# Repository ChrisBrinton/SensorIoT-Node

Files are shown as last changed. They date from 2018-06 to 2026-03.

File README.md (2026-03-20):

# SensorIoT-Node (Deprecated)

> **This repository has been consolidated into [SensorIoT-GW](https://github.com/ChrisBrinton/SensorIoT-GW).**
>
> All sensor node firmware and PCB designs now live under `firmware/node/` and `PCBs/node/` in the consolidated repo.
> This repository is kept for historical reference only.

## Original Description
# SensorIoT-Node
The sensor nodes for the SensorIoT environment

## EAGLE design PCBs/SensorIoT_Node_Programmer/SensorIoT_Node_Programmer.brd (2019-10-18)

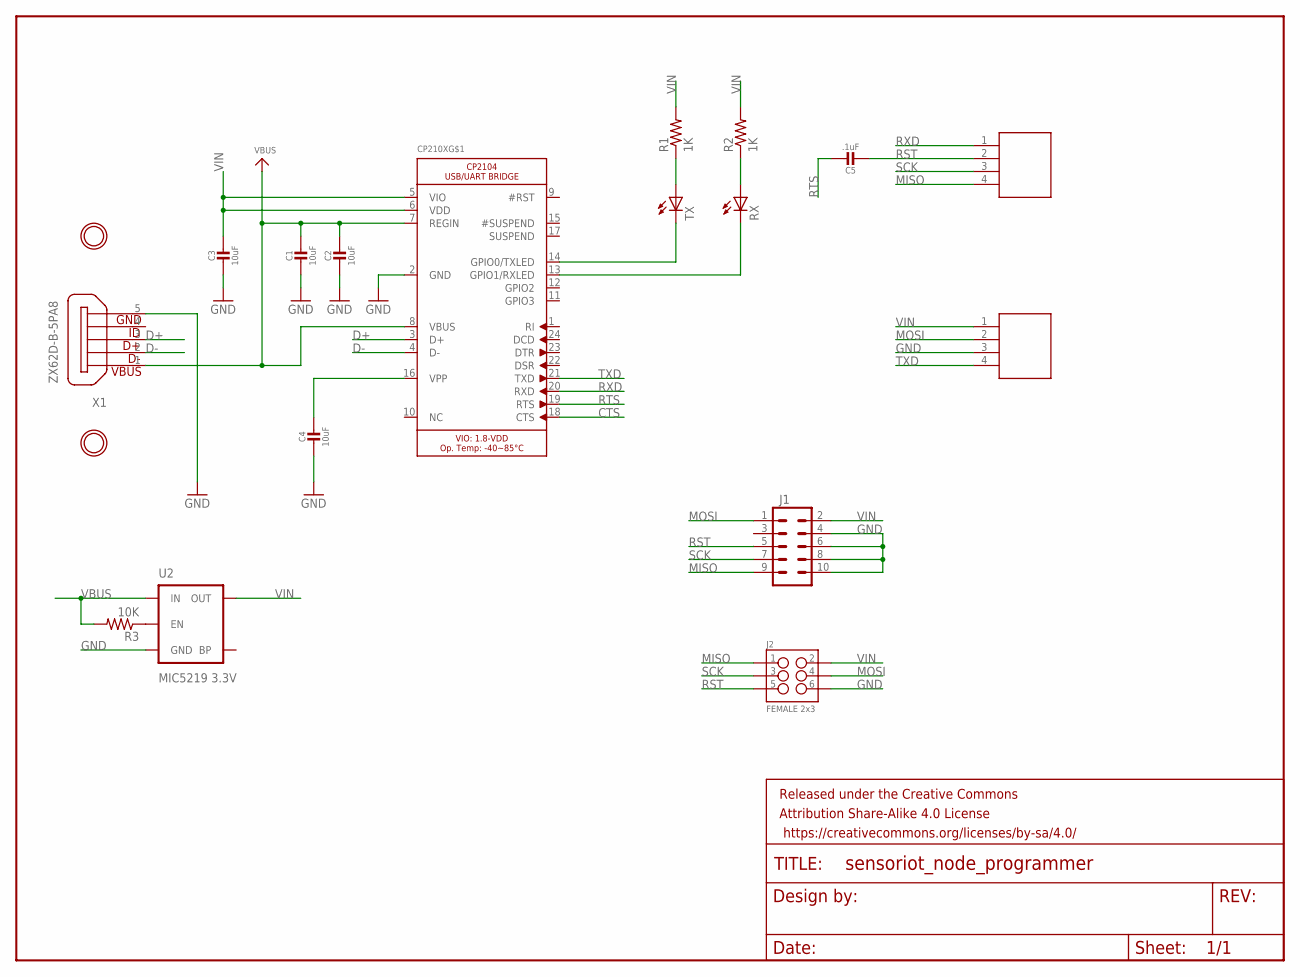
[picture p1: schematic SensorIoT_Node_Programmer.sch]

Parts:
C1, C2, C3, C4: 10uF; _0805
C5: .1uF; _0805
CP210X: CP2104; QFN24_4MM_SMSC
FRAME1: FRAME-LETTER; CREATIVE_COMMONS
J1: M05X2PTH; AVR_ICSP
J2: FEMALE 2x3; 2X3
R1, R2: 1K; 0805
R3: 10K; 0805
RX: LEDCHIP-LED0805; CHIP-LED0805
TX: LEDCHIP-LED0805; CHIP-LED0805
U2: MIC5219 3.3V; SOT23-5
U$2, U$3: MOUNTINGHOLE2.0; MOUNTINGHOLE_2.0_PLATED
U$4, U$5: 4X.1IN_POGO_PIN
X1: ZX62D-B-5PA8

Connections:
CTS: CP210X.18 (CTS)
D+: CP210X.3 (D+), X1.3
D-: CP210X.4 (D-), X1.2
GND: C1.2, C2.2, C3.2, C4.2, CP210X.2 (GND), J1.4, J1.6, J1.8, J1.10, J2.6, U2.2 (GND), U$5.3, X1.5
MISO: J1.9, J2.1, U$4.4
MOSI: J1.1, J2.4, U$5.2
unnamed: C4.1, CP210X.16 (VPP)
unnamed: CP210X.14 (GPIO0/TXLED), TX.C
unnamed: R3.1, U2.3 (EN)
unnamed: CP210X.13 (GPIO1/RXLED), RX.C
unnamed: R1.1, TX.A
unnamed: R2.1, RX.A
RST: C5.2, J1.5, J2.5, U$4.2
RTS: C5.1, CP210X.19 (RTS)
RXD: CP210X.20 (RXD), U$4.1
SCK: J1.7, J2.3, U$4.3
TP: CP210X.THERM (TP)
TXD: CP210X.21 (TXD), U$5.4
VBUS: C1.1, C2.1, CP210X.7 (REGIN), CP210X.8 (VBUS), R3.2, U2.1 (IN), X1.1
VIN: C3.1, CP210X.5 (VIO), CP210X.6 (VDD), J1.2, J2.2, R1.2, R2.2, U2.5 (OUT), U$5.1

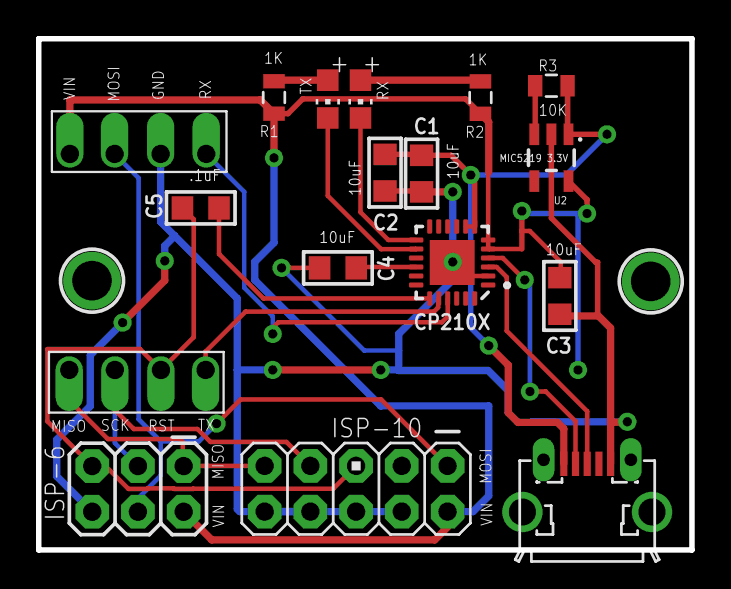
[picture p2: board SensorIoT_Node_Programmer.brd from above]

Board: 2 copper layers, 36.3 x 28.4 mm, 20 parts (0 on the bottom side), 18 nets.

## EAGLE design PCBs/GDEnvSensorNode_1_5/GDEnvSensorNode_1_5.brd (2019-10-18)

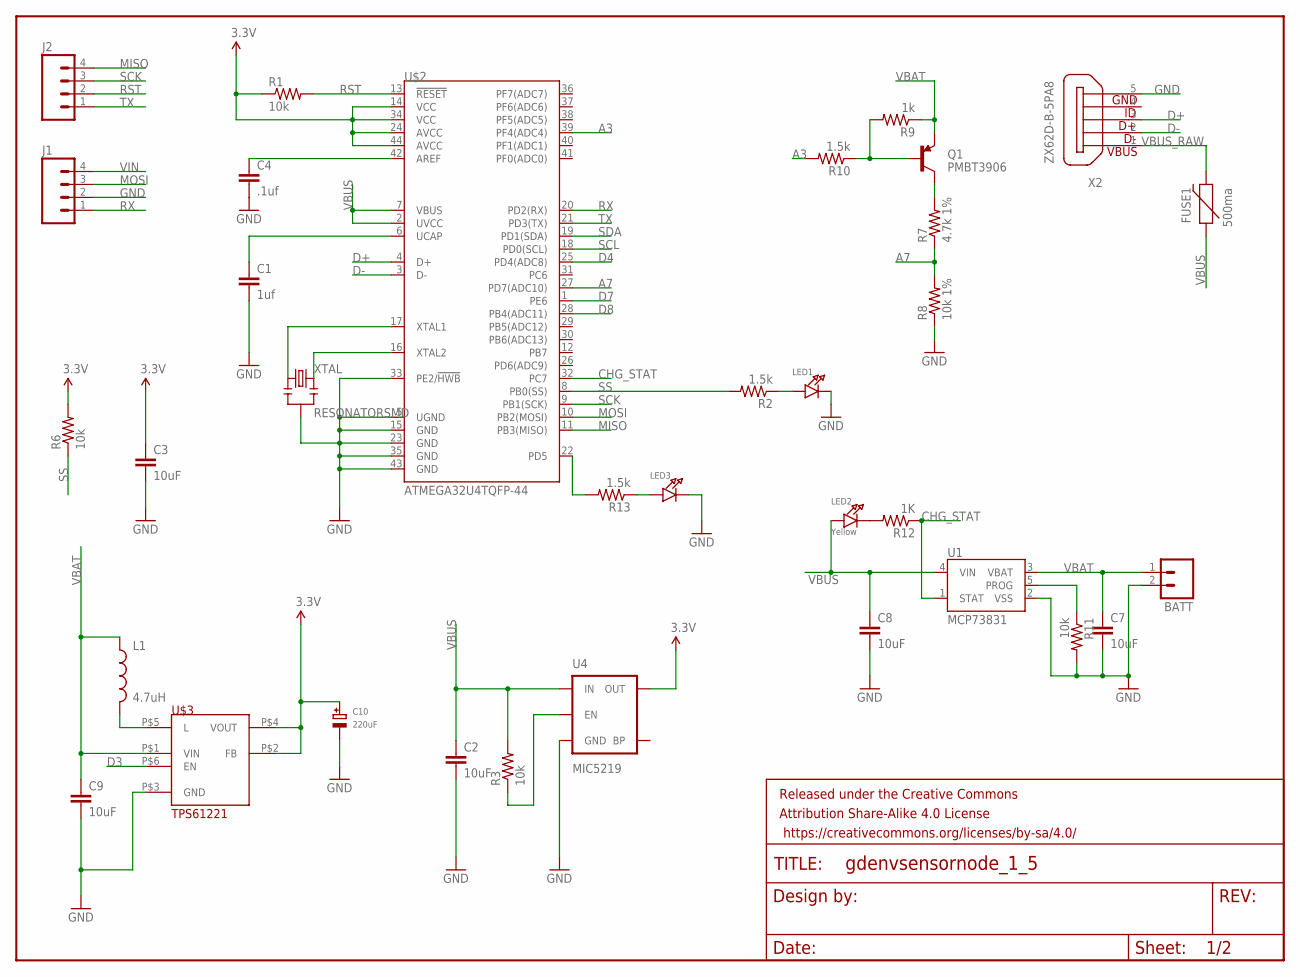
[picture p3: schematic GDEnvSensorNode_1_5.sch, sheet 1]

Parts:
BATT: M02JST-PTH-2; JST-2-PTH
C1: 1uf; 0805
C2, C3, C7, C8, C9: 10uF; 0805
C4: .1uf; 0805
C10: 220uF; EIA3528-21/B-R
FRAME1: FRAME-LETTER; CREATIVE_COMMONS
FUSE1: 500ma; PTC-1206
J1, J2: M04PTH; 1X04
L1: 4.7uH; 1210
LED1, LED3: LED0805; CHIPLED_0805
LED2: Yellow; CHIPLED_0805
Q1: PMBT3906; SOT23-3
R1, R3, R6, R11: 10k; 0805
R2, R10, R13: 1.5k; 0805
R7: 4.7k 1%; 0805
R8: 10k 1%; 0805
R9: 1k; 0805
R12: 1K; 0805
U1: MCP73831; SOT23-5
U4: MIC5219; SOT23-5
U$2: ATMEGA32U4TQFP-44; TQFP44
U$3: TPS61221
X2: ZX62D-B-5PA8
XTAL: RESONATORSMD; RESONATOR-SMD

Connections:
A3: R10.2, U$2.39 (PF4(ADC4))
A7: R7.1, R8.2, U$2.27 (PD7(ADC10))
CHG_STAT: R12.1, U1.1 (STAT), U$2.32 (PC7)
D3: U$3.P$6 (EN)
D4: U$2.25 (PD4(ADC8)); also elsewhere on the board
D7: U$2.1 (PE6); also elsewhere on the board
D8: U$2.28 (PB4(ADC11)); also elsewhere on the board
D+: U$2.4 (D+), X2.3
D-: U$2.3 (D-), X2.2
GND: BATT.2, C1.2, C2.2, C3.2, C4.2, C7.2, C8.2, C9.2, C10.-, J1.2, LED1.C, LED3.C, R8.1, R11.2, U1.2 (VSS), U4.2 (GND), U$2.5 (UGND), U$2.15 (GND), U$2.23 (GND), U$2.33 (PE2/!HWB), U$2.35 (GND), U$2.43 (GND), U$3.P$3 (GND), X2.5, XTAL.2; also elsewhere on the board
L: L1.2, U$3.P$5 (L)
MISO: J2.4, U$2.11 (PB3(MISO)); also elsewhere on the board
MOSI: J1.3, U$2.10 (PB2(MOSI)); also elsewhere on the board
unnamed: U$2.16 (XTAL2), XTAL.3
unnamed: U$2.17 (XTAL1), XTAL.1
unnamed: LED1.A, R2.1
unnamed: LED2.C, R12.2
unnamed: C4.1, U$2.42 (AREF)
unnamed: LED3.A, R13.1
unnamed: R3.1, U4.3 (EN)
unnamed: Q1.1 (B), R9.2, R10.1
unnamed: Q1.3 (C), R7.2
unnamed: R13.2, U$2.22 (PD5)
unnamed: R11.1, U1.5 (PROG)
unnamed: C1.1, U$2.6 (UCAP)
RST: J2.2, R1.2, U$2.13 (!RESET)
RX: J1.1, U$2.20 (PD2(RX))
SCK: J2.3, U$2.9 (PB1(SCK)); also elsewhere on the board
SCL: U$2.18 (PD0(SCL)); also elsewhere on the board
SDA: U$2.19 (PD1(SDA)); also elsewhere on the board
SS: R2.2, R6.1, U$2.8 (PB0(SS))
TX: J2.1, U$2.21 (PD3(TX))
VBAT: BATT.1, C7.1, C9.1, L1.1, Q1.2 (E), R9.1, U1.3 (VBAT), U$3.P$1 (VIN)
VBUS: C2.1, C8.1, FUSE1.1, LED2.A, R3.2, U1.4 (VIN), U4.1 (IN), U$2.2 (UVCC), U$2.7 (VBUS)
VBUS_RAW: FUSE1.2, X2.1
VIN: J1.4

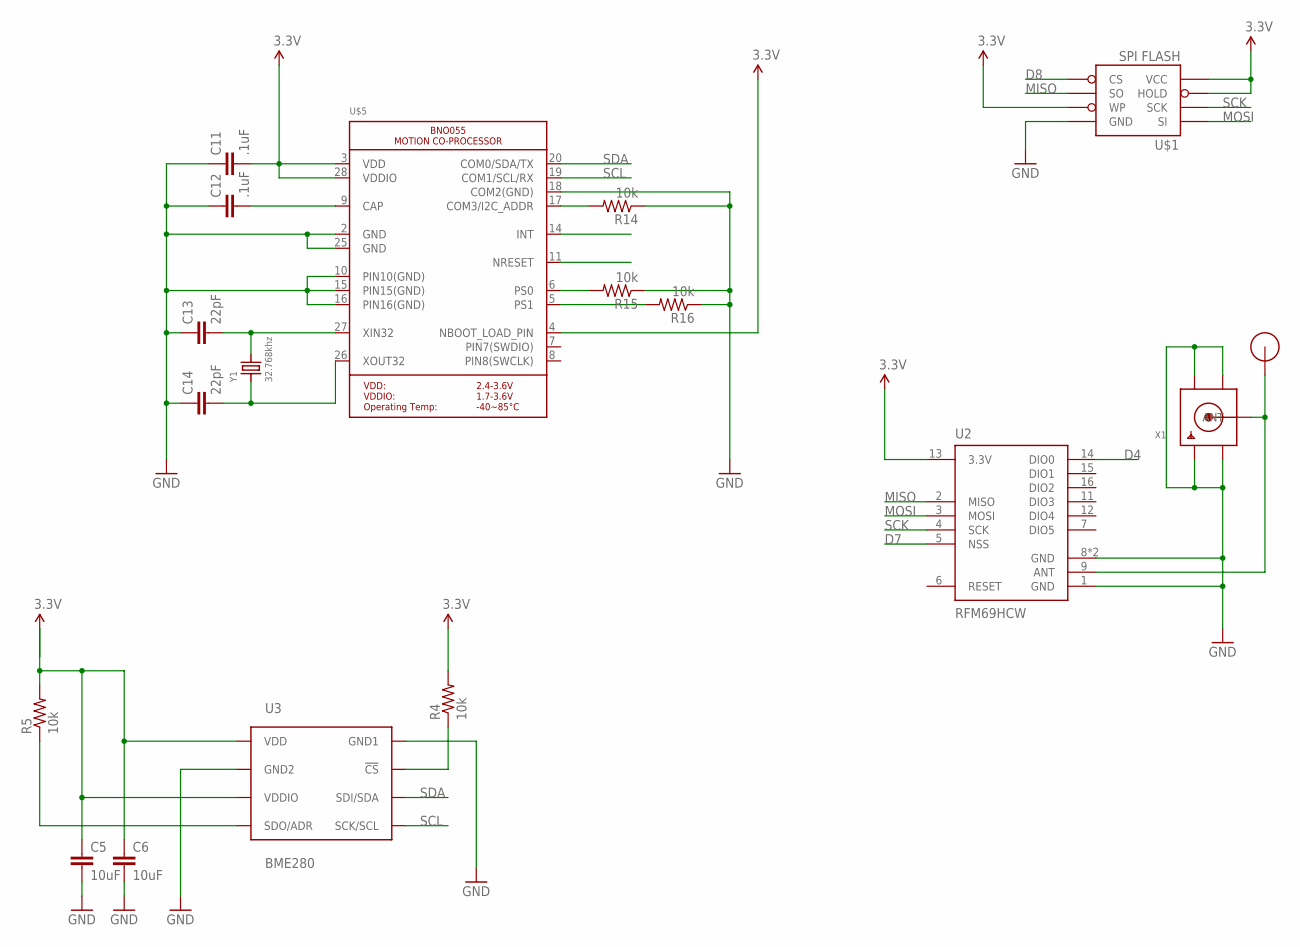
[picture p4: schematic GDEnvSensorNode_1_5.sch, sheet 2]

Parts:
C5, C6: 10uF; 0805
C11, C12: .1uF; 0805
C13, C14: 22pF; 0805
R4, R5, R14, R15, R16: 10k; 0805
U2: RFM69HCW; RFM69HCW-XXXS2
U3: BME280; BME280_LGA
U$1: SPI FLASH; SO08
U$4: RFM12B_ANTENNA; RFM12B-ANTENNA
U$5: MICROBUILDER_BNO055
X1: SMACONNECTOR_EDGE_UFL; SMA_EDGELAUNCH_UFL
Y1: 32.768khz; CRYSTAL_8X3.8

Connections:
ANT: U2.9 (ANT), U$4.P$1, X1.P (ANT)
D4: U2.14 (DIO0); also elsewhere on the board
D7: U2.5 (NSS); also elsewhere on the board
D8: U$1.1_CS (CS); also elsewhere on the board
GND: C5.2, C6.2, C11.1, C12.1, C13.1, C14.1, R14.1, R15.1, R16.1, U2.1 (GND), U2.8 (GND), U2.10 (GND), U3.P$1 (GND1), U3.P$7 (GND2), U$1.4_GND (GND), U$5.2 (GND), U$5.10 (PIN10(GND)), U$5.15 (PIN15(GND)), U$5.16 (PIN16(GND)), U$5.18 (COM2(GND)), U$5.25 (GND), X1.GND@1 (GND1), X1.GND@2 (GND2), X1.GND@3 (GND3), X1.GND@4 (GND4); also elsewhere on the board
MISO: U2.2 (MISO), U$1.2_SO (SO); also elsewhere on the board
MOSI: U2.3 (MOSI), U$1.5_SI (SI); also elsewhere on the board
unnamed: R4.1, U3.P$2 (!CS)
unnamed: C12.2, U$5.9 (CAP)
unnamed: C5.1, C6.1, R5.2, U3.P$6 (VDDIO), U3.P$8 (VDD)
unnamed: R5.1, U3.P$5 (SDO/ADR)
unnamed: C13.2, U$5.27 (XIN32), Y1.P$4 (2)
unnamed: C14.2, U$5.26 (XOUT32), Y1.P$1 (1)
unnamed: R14.2, U$5.17 (COM3/I2C_ADDR)
unnamed: R15.2, U$5.6 (PS0)
unnamed: R16.2, U$5.5 (PS1)
SCK: U2.4 (SCK), U$1.6_SCK (SCK); also elsewhere on the board
SCL: U3.P$4 (SCK/SCL), U$5.19 (COM1/SCL/RX); also elsewhere on the board
SDA: U3.P$3 (SDI/SDA), U$5.20 (COM0/SDA/TX); also elsewhere on the board

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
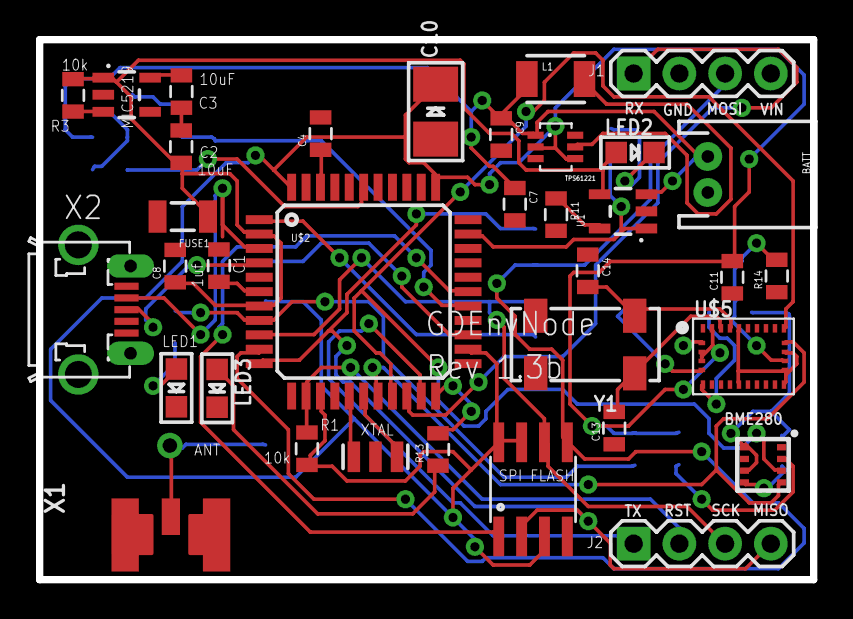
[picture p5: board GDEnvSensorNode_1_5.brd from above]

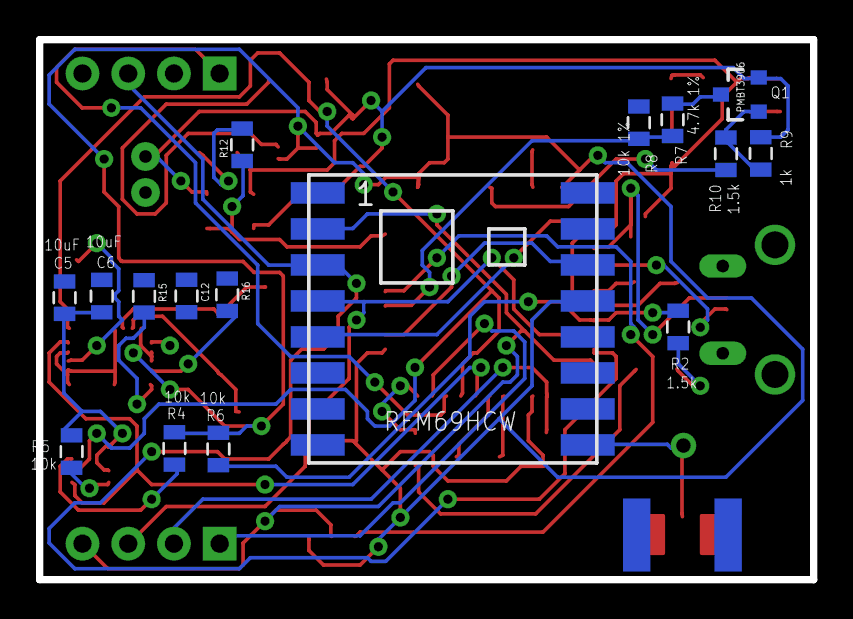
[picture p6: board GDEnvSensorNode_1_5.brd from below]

Board: 2 copper layers, 43.0 x 30.0 mm, 53 parts (16 on the bottom side), 46 nets.

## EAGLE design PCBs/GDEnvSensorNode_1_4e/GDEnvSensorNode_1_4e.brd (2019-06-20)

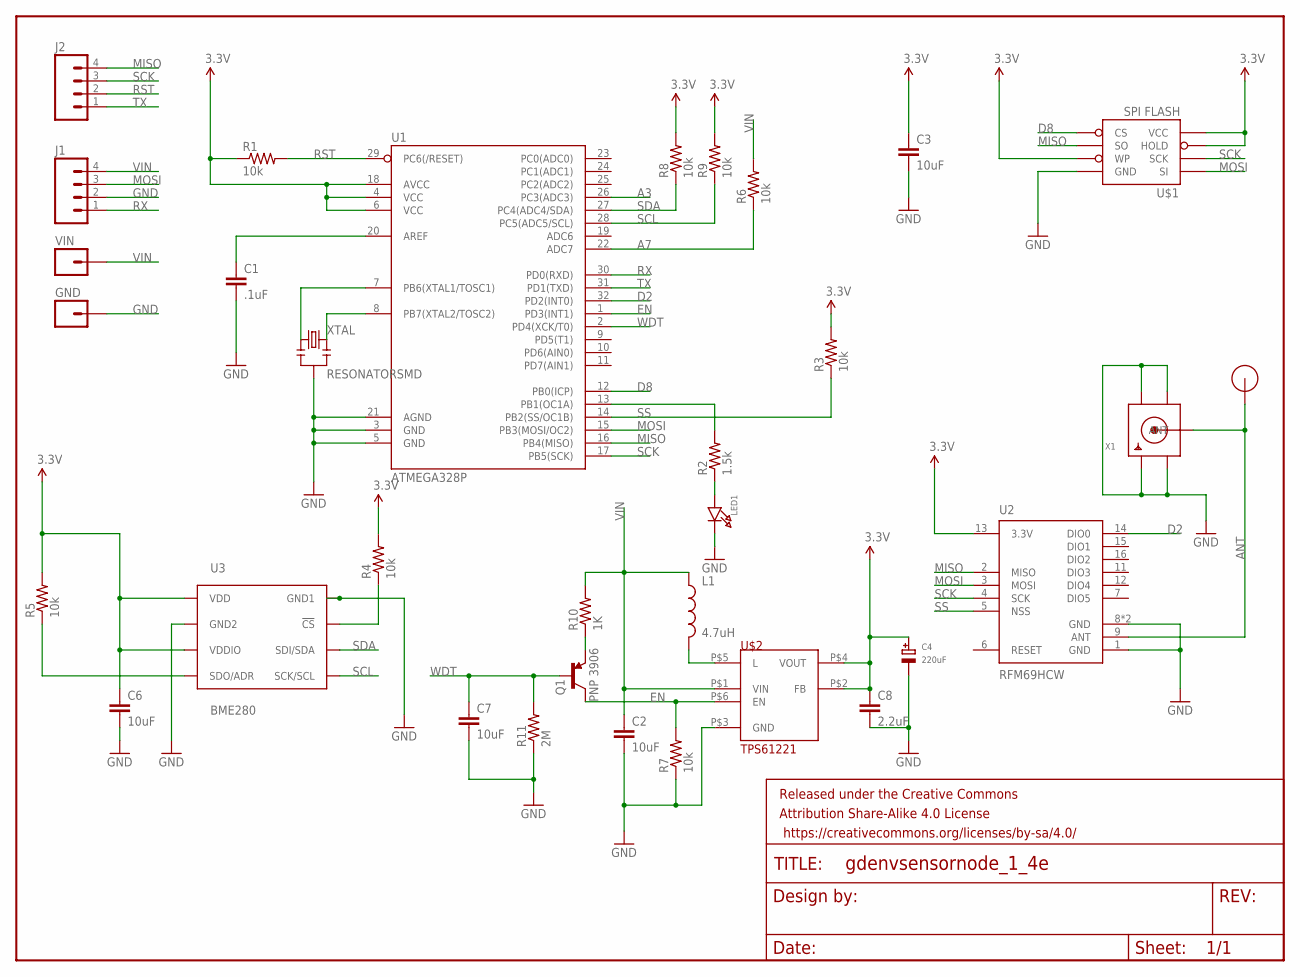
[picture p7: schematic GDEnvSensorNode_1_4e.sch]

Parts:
C1: .1uF; 0805
C2, C3, C6, C7: 10uF; 0805
C4: 220uF; EIA7343-31/D-R
C8: 2.2uF; 0805
FRAME1: FRAME-LETTER; CREATIVE_COMMONS
GND: M01PTH_2MM; 1X01_2MM
J1, J2: M04PTH; 1X04
L1: 4.7uH; 1210
LED1: LED0805; CHIPLED_0805
Q1: PNP 3906; SOT23-3
R1, R3, R4, R5, R6, R7, R8, R9: 10k; 0805
R2: 1.5k; 0805
R10: 1K; R0805
R11: 2M; R0805
U1: ATMEGA328P; TQFP32-08
U2: RFM69HCW; RFM69HCW-XXXS2
U3: BME280; BME280_LGA
U$1: SPI FLASH; SO08
U$2: TPS61221
U$4: RFM12B_ANTENNA; RFM12B-ANTENNA
VIN: M01PTH_2MM; 1X01_2MM
X1: SMACONNECTOR_EDGE_UFL; SMA_EDGELAUNCH_UFL
XTAL: RESONATORSMD; RESONATOR-SMD

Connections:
3.3V: C3.1, C4.+, C6.1, C8.1, R1.1, R3.2, R4.2, R5.2, R8.2, R9.2, U1.4 (VCC), U1.6 (VCC), U1.18 (AVCC), U2.13 (3.3V), U3.P$6 (VDDIO), U3.P$8 (VDD), U$1.3_WP (WP), U$1.7_HOLD (HOLD), U$1.8_VCC (VCC), U$2.P$2 (FB), U$2.P$4 (VOUT)
A3: U1.26 (PC3(ADC3))
A7: R6.1, U1.22 (ADC7)
ANT: U2.9 (ANT), U$4.P$1, X1.P (ANT)
D2: U1.32 (PD2(INT0)), U2.14 (DIO0)
D8: U1.12 (PB0(ICP)), U$1.1_CS (CS)
EN: Q1.3 (C), R7.2, U1.1 (PD3(INT1)), U$2.P$6 (EN)
GND: C1.2, C2.2, C3.2, C4.-, C6.2, C7.2, C8.2, GND.1, J1.2, LED1.C, R7.1, R11.1, U1.3 (GND), U1.5 (GND), U1.21 (AGND), U2.1 (GND), U2.8 (GND), U2.10 (GND), U3.P$1 (GND1), U3.P$7 (GND2), U$1.4_GND (GND), U$2.P$3 (GND), X1.GND@1 (GND1), X1.GND@2 (GND2), X1.GND@3 (GND3), X1.GND@4 (GND4), XTAL.2
L: L1.2, U$2.P$5 (L)
MISO: J2.4, U1.16 (PB4(MISO)), U2.2 (MISO), U$1.2_SO (SO)
MOSI: J1.3, U1.15 (PB3(MOSI/OC2)), U2.3 (MOSI), U$1.5_SI (SI)
unnamed: U1.8 (PB7(XTAL2/TOSC2)), XTAL.3
unnamed: U1.7 (PB6(XTAL1/TOSC1)), XTAL.1
unnamed: LED1.A, R2.1
unnamed: Q1.2 (E), R10.1
unnamed: R4.1, U3.P$2 (!CS)
unnamed: R2.2, U1.13 (PB1(OC1A))
unnamed: C1.1, U1.20 (AREF)
unnamed: R5.1, U3.P$5 (SDO/ADR)
RST: J2.2, R1.2, U1.29 (PC6(/RESET))
RX: J1.1, U1.30 (PD0(RXD))
SCK: J2.3, U1.17 (PB5(SCK)), U2.4 (SCK), U$1.6_SCK (SCK)
SCL: R9.1, U1.28 (PC5(ADC5/SCL)), U3.P$4 (SCK/SCL)
SDA: R8.1, U1.27 (PC4(ADC4/SDA)), U3.P$3 (SDI/SDA)
SS: R3.1, U1.14 (PB2(SS/OC1B)), U2.5 (NSS)
TX: J2.1, U1.31 (PD1(TXD))
VIN: C2.1, J1.4, L1.1, R6.2, R10.2, U$2.P$1 (VIN), VIN.1
WDT: C7.1, Q1.1 (B), R11.2, U1.2 (PD4(XCK/T0))

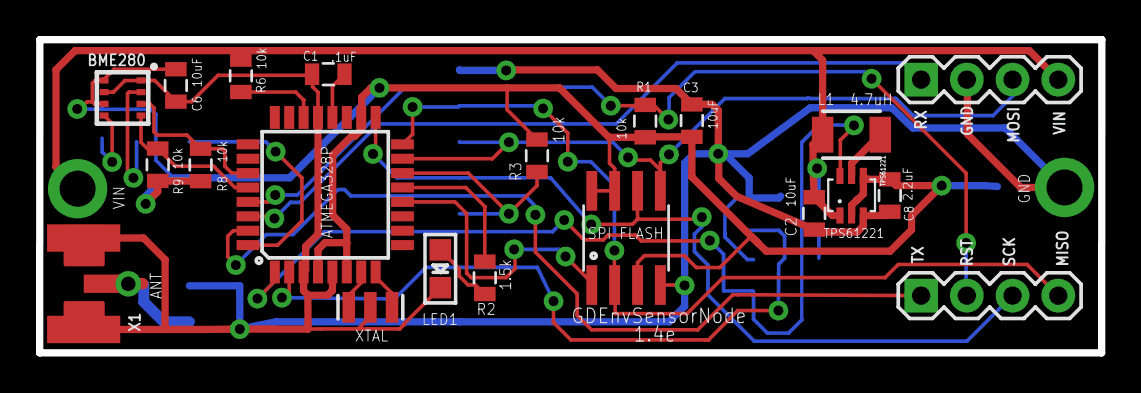
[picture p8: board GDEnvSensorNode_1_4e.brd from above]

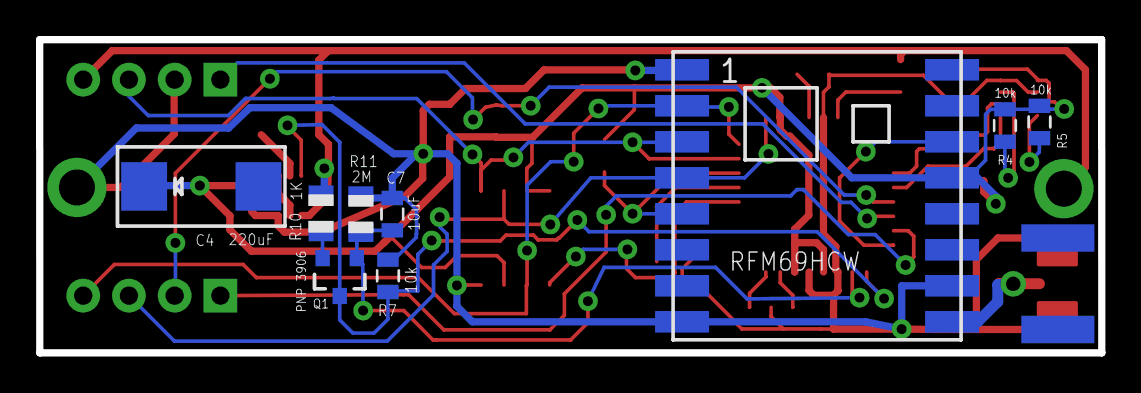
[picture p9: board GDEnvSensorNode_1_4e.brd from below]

Board: 2 copper layers, 59.0 x 17.4 mm, 34 parts (9 on the bottom side), 27 nets.

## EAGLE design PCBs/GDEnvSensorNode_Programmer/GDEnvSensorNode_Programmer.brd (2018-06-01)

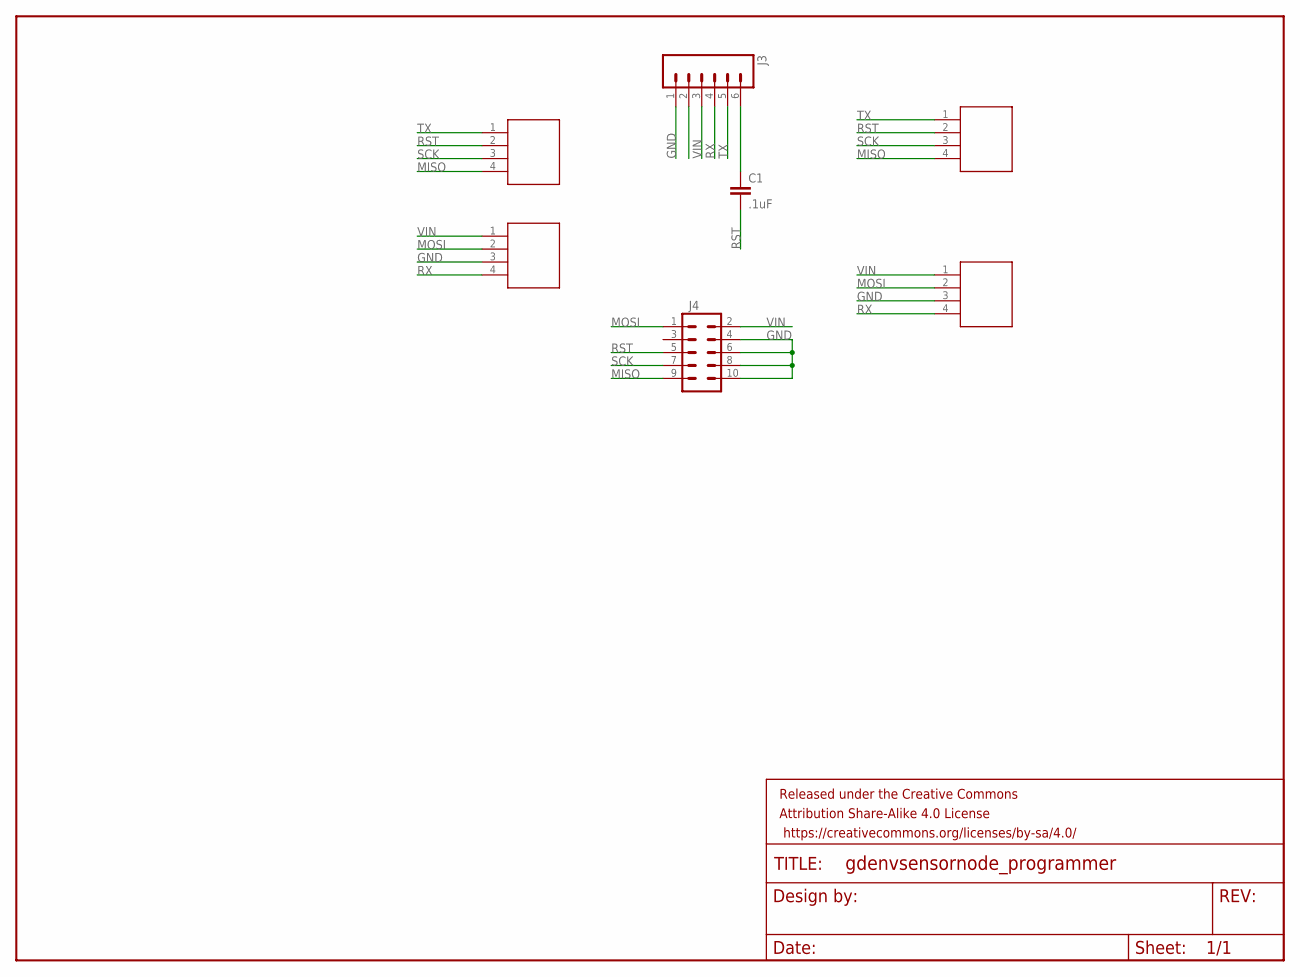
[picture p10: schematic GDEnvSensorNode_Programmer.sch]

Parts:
C1: .1uF; 0805
FRAME1: FRAME-LETTER; CREATIVE_COMMONS
J1, J2, J5, J6: 4X.1IN_POGO_PIN
J3: M06LONGPADS; 1X06_LONGPADS
J4: M05X2PTH; AVR_ICSP

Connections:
GND: J2.3, J3.1, J4.4, J4.6, J4.8, J4.10, J6.3
MISO: J1.4, J4.9, J5.4
MOSI: J2.2, J4.1, J6.2
unnamed: C1.1, J3.6
RST: C1.2, J1.2, J4.5, J5.2
RX: J2.4, J3.4, J6.4
SCK: J1.3, J4.7, J5.3
TX: J1.1, J3.5, J5.1
VIN: J2.1, J3.3, J4.2, J6.1

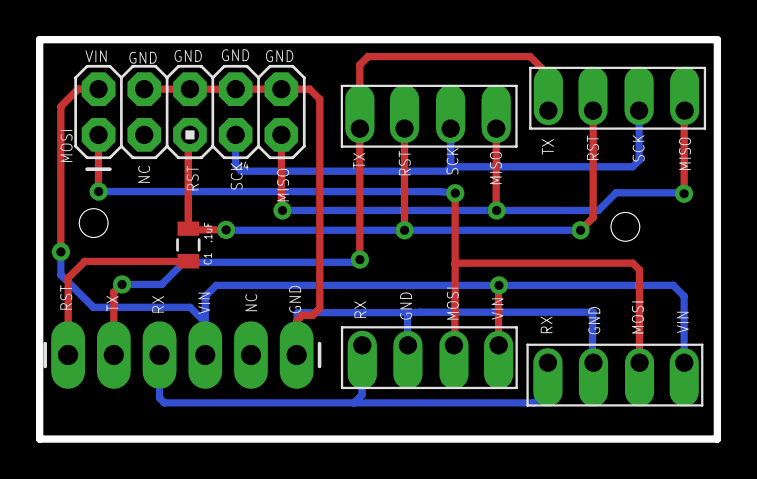
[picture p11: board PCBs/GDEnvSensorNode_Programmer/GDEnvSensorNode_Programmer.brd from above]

Board: 2 copper layers, 37.6 x 22.2 mm, 8 parts (0 on the bottom side), 9 nets.

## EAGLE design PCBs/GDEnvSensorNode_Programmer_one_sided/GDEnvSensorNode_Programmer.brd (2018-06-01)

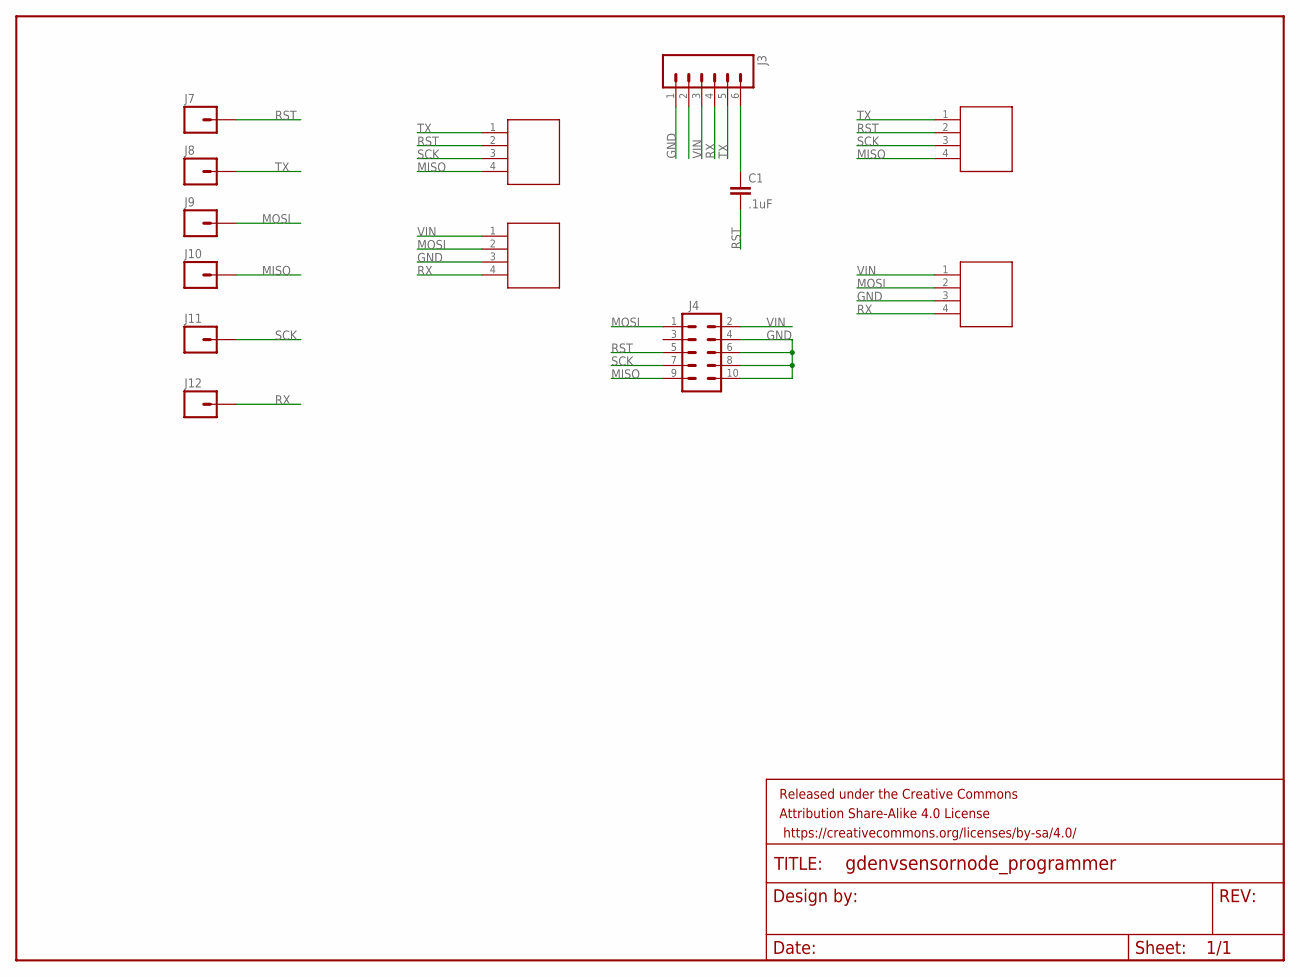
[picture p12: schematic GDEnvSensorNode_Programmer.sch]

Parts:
C1: .1uF; 0805
FRAME1: FRAME-LETTER; CREATIVE_COMMONS
J1, J2, J5, J6: 4X.1IN_POGO_PIN
J3: M06LONGPADS; 1X06_LONGPADS
J4: M05X2PTH; AVR_ICSP
J7, J8, J9, J10, J11, J12: M01PTH; 1X01

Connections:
GND: J2.3, J3.1, J4.4, J4.6, J4.8, J4.10, J6.3
MISO: J1.4, J4.9, J5.4, J10.1
MOSI: J2.2, J4.1, J6.2, J9.1
unnamed: C1.1, J3.6
RST: C1.2, J1.2, J4.5, J5.2, J7.1
RX: J2.4, J3.4, J6.4, J12.1
SCK: J1.3, J4.7, J5.3, J11.1
TX: J1.1, J3.5, J5.1, J8.1
VIN: J2.1, J3.3, J4.2, J6.1


Board: 2 copper layers, 31.6 x 30.2 mm, 14 parts (0 on the bottom side), 9 nets.

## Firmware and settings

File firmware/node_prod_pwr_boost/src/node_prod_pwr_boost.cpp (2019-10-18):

//node_prod_pwr_boost is based on the low power labs Moteino and WeatherSheild R2 with subsequent changes.

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
// License can be viewed at                               
// http://www.gnu.org/licenses/gpl-3.0.txt
//
// Please maintain this license information along with authorship
// and copyright notices in any redistribution of this code
// **********************************************************************************
#include <node_prod_pwr_boost.h>
#include <RFM69.h>         //get it here: https://github.com/lowpowerlab/rfm69
#include <RFM69_ATC.h>     //get it here: https://github.com/lowpowerlab/rfm69
#include <SPIFlash.h>      //get it here: https://github.com/lowpowerlab/spiflash
#include <SPI.h>           //included in Arduino IDE (www.arduino.cc)
#include <Wire.h>          //included in Arduino IDE (www.arduino.cc)
#include <SparkFunBME280.h>//get it here: https://github.com/sparkfun/SparkFun_BME280_Breakout_Board/tree/master/Libraries/Arduino/src
#include <LowPower.h>      //get it here: https://github.com/lowpowerlab/lowpower
                           //writeup here: http://www.rocketscream.com/blog/2011/07/04/lightweight-low-power-arduino-library/

//*********************************************************************************************
//************ IMPORTANT SETTINGS - YOU MUST CHANGE/CONFIGURE TO FIT YOUR HARDWARE ************
//*********************************************************************************************
#define GATEWAYID   1
#define NODEID      84 //86 was the last - below 40 are test&debug nodes
#define NETWORKID   100
//#define FREQUENCY     RF69_433MHZ
//#define FREQUENCY     RF69_868MHZ
#define FREQUENCY       RF69_915MHZ //Match this with the version of your Moteino! (others: RF69_433MHZ, RF69_868MHZ)
#define ENCRYPTKEY      "sampleEncryptKey" //has to be same 16 characters/bytes on all nodes, not more not less!
#define IS_RFM69HW    //uncomment only for RFM69HW! Leave out if you have RFM69W!
//*********************************************************************************************
#define ENABLE_ATC    //comment out this line to disable AUTO TRANSMISSION CONTROL
#define ATC_RSSI      -75
//*********************************************************************************************
#define SEND_LOOPS   75 //send data this many sleep loops (75 loops of 8sec cycles = 600sec ~ 10 minutes)
#define SLEEP_FASTEST SLEEP_15MS
#define SLEEP_FAST SLEEP_250MS
#define SLEEP_SEC SLEEP_1S
#define SLEEP_LONG SLEEP_2S
#define SLEEP_LONGER SLEEP_4S
#define SLEEP_LONGEST SLEEP_8S
period_t sleepTime = SLEEP_4S; //period_t is an enum type defined in the LowPower library (LowPower.h)
//*********************************************************************************************
#define BATT_MONITOR_EN A3 //enables battery voltage divider to get a reading from a battery, disable it to save power
#define BATT_MONITOR  A7   //The 1.4h node can read the VIN line directly due to the boost circuit that is used as a reference
#define BATT_CYCLES   2    //read and report battery voltage every this many sleep cycles (ex 30cycles * 8sec sleep = 240sec/4min). For 450 cyclesyou would get ~1 hour intervals
//#define BATT_FORMULA(reading) reading * 0.00322 // >>> fine tune this parameter to match your voltage when fully charged
#define BATT_FORMULA(reading) ((reading * 0.00437)+ .54)/1.68  // >>> Tuned for 1.4h node
#define BATT_LOW      3.6  //(volts)
#define BATT_READ_LOOPS  SEND_LOOPS*10  // read and report battery voltage every this many sleep cycles (ex 30cycles * 8sec sleep = 240sec/4min). For 450 cycles you would get ~1 hour intervals between readings
//*****************************************************************************************************************************
//*****************************
#define POWER_BOOST_EN 3
#define TRANSMIT_COUNTER 150 //150*4s = 10min - multiply the transmit counter * sleep time to determine transmit interval
//*****************************

#ifdef __AVR_ATmega1284P__
  #define LED           15 // Moteino MEGAs have LEDs on D15
  #define FLASH_SS      23 // and FLASH SS on D23
#else
  #define LED           9 // Moteinos have LEDs on D9
  #define FLASH_SS      8 // and FLASH SS on D8
#endif

#define BLINK_EN                 //uncomment to blink LED on every send
#define SERIAL_EN                //comment out if you don't want any serial output

#ifdef SERIAL_EN
  #define SERIAL_BAUD   115200
  #define DEBUG(input)   {Serial.print(input);}
  #define DEBUGln(input) {Serial.println(input);}
  #define SERIALFLUSH() {Serial.flush();}
#else
  #define DEBUG(input);
  #define DEBUGln(input);
  #define SERIALFLUSH();
#endif
//*****************************************************************************************************************************

#ifdef ENABLE_ATC
  RFM69_ATC radio;
#else
  RFM69 radio;
#endif

SPIFlash flash(FLASH_SS, 0xEF30); //WINDBOND 4MBIT flash chip on CS pin D8 (default for Moteino)

BME280 bme280;
char Pstr[10];
char Fstr[10];
char Hstr[10];
char buffer[50];
int cycles,powerCycles,readCycles;
double F,P,H;

void setup(void)
{
#ifdef SERIAL_EN
  Serial.begin(SERIAL_BAUD);
#endif
  pinMode(LED, OUTPUT);

  sprintf(buffer, "SensorIoT Node - Network ID %d Gateway ID %d", NETWORKID, NODEID);
  DEBUGln(buffer);

  DEBUGln("Setting up device");

  enablePowerBoost(); //enable the power boost circuit during setup and initialization

  cycles=0;
  powerCycles=0;
  readCycles=0;
  
  //initialize weather shield BME280 sensor
  bme280.settings.commInterface = I2C_MODE;
  bme280.settings.I2CAddress = 0x77;
  bme280.settings.runMode = 3; //Normal mode
  bme280.settings.tStandby = 0;
  bme280.settings.filter = 0;
  bme280.settings.tempOverSample = 1;
  bme280.settings.pressOverSample = 1;
  bme280.settings.humidOverSample = 1;

  DEBUGln("Initializing and sleeping BME280");

  
  bme280.begin();
  P = bme280.readFloatPressure() * 0.0002953; //read Pa and convert to inHg
  F = bme280.readTempF();
  H = bme280.readFloatHumidity();
  bme280.writeRegister(BME280_CTRL_MEAS_REG, 0x00); //sleep the BME280
  
  
  DEBUGln("Blinking LED");
  
  Blink(LED, 100);Blink(LED, 100);Blink(LED, 100);

  DEBUGln("Initializing radio");

  
  radio.initialize(FREQUENCY,NODEID,NETWORKID);
#ifdef IS_RFM69HW
  radio.setHighPower(); //uncomment only for RFM69HW!
#endif
  radio.encrypt(ENCRYPTKEY);


//Auto Transmission Control - dials down transmit power to save battery (-100 is the noise floor, -90 is still pretty good)
//For indoor nodes that are pretty static and at pretty stable temperatures (like a MotionMote) -90dBm is quite safe
//For more variable nodes that can expect to move or experience larger temp drifts a lower margin like -70 to -80 would probably be better
//Always test your ATC mote in the edge cases in your own environment to ensure ATC will perform as you expect
#ifdef ENABLE_ATC
  radio.enableAutoPower(ATC_RSSI);
#endif

  sprintf(buffer, "Transmitting at: %d Mhz...", FREQUENCY==RF69_433MHZ ? 433 : FREQUENCY==RF69_868MHZ ? 868 : 915);
  DEBUGln(buffer);

  radio.sleep();
  SERIALFLUSH();
}

unsigned long doorPulseCount = 0;
char input=0;
byte sendLoops=0;
byte battReadLoops=0;
float batteryVolts = 5;
char* BATstr="BAT:5.00v"; //longest battery voltage reading message = 9chars
byte sendLen;

void loop()
{
  enablePowerBoost();

  if(readCycles > TRANSMIT_COUNTER) {
    Blink(LED, 8); // 50ma * 5ms
    delay(2); //Dont read bat voltage for at least 10 millis (3 for enable, 5 for led blink, so 2 more here)
    readBattery(); //50ma * .35ms
    readCycles=0;


    //read BME sensor
    bme280.begin();
    P = bme280.readFloatPressure() * 0.0002953; //read Pa and convert to inHg
    F = bme280.readTempF();
    H = bme280.readFloatHumidity();
    bme280.writeRegister(BME280_CTRL_MEAS_REG, 0x00); //sleep the BME280


    dtostrf(F, 3,2, Fstr);
    dtostrf(H, 3,2, Hstr);
    dtostrf(P, 3,2, Pstr);
    DEBUGln(Fstr);

    sprintf(buffer, "BAT:%sv F:%s H:%s P:%s", BATstr, Fstr, Hstr, Pstr);

    sendLen = strlen(buffer);
    radio.sendWithRetry(GATEWAYID, buffer, sendLen, 1); //retry one time
    DEBUG(buffer); DEBUG(" (packet length:"); DEBUG(sendLen); DEBUGln(")");
 
  }
  
  radio.sleep();

  //The rest of the loop costs 10ma * 4ms
  disablePowerBoost();
  SERIALFLUSH();
  LowPower.powerDown(sleepTime, ADC_OFF, BOD_OFF);
  readCycles++;
  cycles++;
  DEBUG(cycles);
  DEBUGln(" WAKEUP");
}

void enablePowerBoost()
{
  pinMode(POWER_BOOST_EN, OUTPUT);
  digitalWrite(POWER_BOOST_EN, HIGH);
  DEBUGln("Power boost on");
  delay(3); //hackey atm, but lets try holding the boost on a bit longer and see if the power stabilizes a bit
}

void disablePowerBoost()
{
  digitalWrite(POWER_BOOST_EN, LOW);
  pinMode(POWER_BOOST_EN, INPUT);
  DEBUGln("Power boost off");
}

void readBattery()
{
  unsigned int readings=0;
  
  //enable battery monitor on WeatherShield (via mosfet controlled by A3)
  //pinMode(BATT_MONITOR_EN, OUTPUT);
  //digitalWrite(BATT_MONITOR_EN, LOW);

  //take several samples, and average
  for (byte i=0; i<5; i++) {
    unsigned int reading=0;
    reading = analogRead(BATT_MONITOR);
    DEBUG("raw ");
    DEBUGln(reading);
    batteryVolts = BATT_FORMULA(reading);
    dtostrf(batteryVolts,3,2, BATstr);
    DEBUGln(BATstr);
    
    readings+=reading;
  }
  
  //disable battery monitor
  pinMode(BATT_MONITOR_EN, INPUT); //highZ mode will allow p-mosfet to be pulled high and disconnect the voltage divider on the weather shield
    
  batteryVolts = BATT_FORMULA(readings / 5.0);
  dtostrf(batteryVolts,3,2, BATstr); //update the BATStr which gets sent every BATT_CYCLES or along with the MOTION message
  //if (batteryVolts <= BATT_LOW) BATstr = "LOW";
  DEBUG("Average reading: ");
  DEBUGln(BATstr);
}

void Blink(byte PIN, byte DELAY_MS)
{
  pinMode(PIN, OUTPUT);
  digitalWrite(PIN,HIGH);
  delay(DELAY_MS/2);
  digitalWrite(PIN,LOW);
  delay(DELAY_MS/2);  
}

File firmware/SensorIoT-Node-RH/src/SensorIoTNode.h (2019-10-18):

#include <SPI.h>                //builtin
#include <RHReliableDatagram.h> //part of RadioHead - Platformio ID#124
#include <SPIFlash.h>           //Platformio ID#125
#include <Wire.h>               //builtin
#include <SparkFunBME280.h>     //Platformio ID#684
#include <LowPower.h>           //Platformio ID#38

//******************************************************
//*******           Hardware Config              *******
//******************************************************
// Select radio - only uncomment one!
#define IS_RF95
//#define IS_RFM69
//#define IS_RFM69HW    //uncomment only for RFM69HW! Leave out if you have RFM69W!
#define RF95_MODEM_CONFIG RH_RF95::Bw125Cr45Sf128

// Singleton instance of the radio driver
#ifdef IS_RF95
  #include <RH_RF95.h>            //part of RadioHead - Platformio ID#124
  RH_RF95 driver;
  #define MAX_MESSAGE_LEN     RH_RF95_MAX_MESSAGE_LEN
  #define MINTXPOWER          5
  #define MAXTXPOWER          15
#endif
#if defined (IS_RFM69) || defined (IS_RFM69HW)
  #include <RH_RF69.h>            //part of RadioHead - Platformio ID#124
  RH_RF69 driver;
  #define MAX_MESSAGE_LEN     RH_RF69_MAX_MESSAGE_LEN
  #define MINTXPOWER          -2
  #define MAXTXPOWER          20
#endif

// Select frequency - only uncomment one!
//#define FREQUENCY       433
//#define FREQUENCY       868
#define FREQUENCY       915

#define BATT_MONITOR  A7   //The 1.4e and greater nodes can read the VIN line directly. VIN should be 1.6V or less and after it stabilizing the boost side will provide a 3.3V reference.
#define BATT_FORMULA(reading) ((reading * 0.00437)+ .54)/1.68  // >>> Tuned for 1.4h node

#define POWER_BOOST_EN 3

#define LED           9 // SensorIoT Nodes have LEDs on D9
//#define FLASH_EN
#define FLASH_SS      8 // and FLASH SS on D8 (Like Moteinos)
#define SERIAL_EN       // uncomment to enable Serial output

#define BLINK_EN        //uncomment to blink LED on every send

#ifdef SERIAL_EN
  #define SERIAL_BAUD   115200
  #define DEBUG(input)   {Serial.print(input);}
  #define DEBUGln(input) {Serial.println(input);}
  #define SERIALFLUSH() {Serial.flush();}
#else
  #define DEBUG(input);
  #define DEBUGln(input);
  #define SERIALFLUSH();
#endif



//******************************************************
//*******              Node Config               *******
//******************************************************
#define VERSION      "1.1.1"
#define GATEWAY_ID   1
#define NODE_ID      96 //94 was the last - below 40 are test&debug nodes
#define SECSBETWEENXMITS  600 //(20 for test, 600 for prod) wait this many secs between xmits. This is approximate based on how long the node sleeps every loop.
/*
  LOOPSWITHACK is the number of successful xmit loops that will happen before the node stops waiting for ACKs and CtrlMsgs. Waiting
  several seconds with the reciever on and then ACKing the ACK is quite a drain on the battery over months. Everytime the node starts
  it will wait this many loops to let the GW and Node settle on the appropriate tx power. Everytime the node restarts this process will
  begin again.
*/
#define LOOPSWITHACK      50 
//period_t is an enum type defined in the LowPower library (LowPower.h)
period_t currentSleepTime = SLEEP_1S; //start at 1S, this will be dynamically increased if the xmit loop is stable.
/* BATT_READ_LOOPS - read and report battery voltage every this many sleep cycles (ex 30cycles * 8sec sleep = 240sec/4min).
                     For 450 cycles you would get ~1 hour intervals between readings
*/
#define BATT_READ_LOOPS  SEND_LOOPS*10  //  





// Class to manage message delivery and receipt, using the driver declared above
RHReliableDatagram radio(driver, NODE_ID);


#ifdef FLASH_EN
  SPIFlash flash(FLASH_SS, 0xEF30); //WINDBOND 4MBIT flash chip on CS pin D8 (default for Moteino)
#endif

//The nodeStatus byte is 8 status bits as defined below
uint8_t nodeStatus;
#define NODESTATUS_FIRSTLOOP    1
#define NODESTATUS_XMIT_SUCCESS 2
#define NODESTATUS_WAIT_FOR_ACK 4 //Will be true if the node is requesting and waiting for ACKs from the GW
#define NODESTATUS_MAX_POWER    8
#define NODESTATUS_MIN_POWER    16



BME280 bme280;
char Pstr[10];
char Fstr[10];
char Hstr[10];
uint8_t buffer[MAX_MESSAGE_LEN];
double F,P,H;
uint8_t _txPower;
char STStr[4];
char TxStr[4];
uint8_t sleepLevel;
uint8_t stateByte;
char input=0;
uint8_t loopSuccess=0;
uint16_t loopCounter=0;
byte battReadLoops=0;
float batteryVolts = 1.5;
char BATstr[10]="BAT:1.50v"; //longest battery voltage reading message = 9chars
byte sendLen;
uint16_t secsSinceXmit, secsBetweenXmit;
uint16_t currentMillis=0;



void enablePowerBoost();
void disablePowerBoost();
void readBattery();
void Blink(byte PIN, byte DELAY_MS);
void handleControlMsg(char* msg);
uint8_t getCurrentSleepTime();
void setNextSleepTime();
void sendWithoutCtrlMsg();
void sendWithCtrlMsg();
void printMillis();

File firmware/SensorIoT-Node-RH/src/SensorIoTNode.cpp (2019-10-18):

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
// Licence can be viewed at                               
// http://www.gnu.org/licenses/gpl-3.0.txt
//
// Please maintain this license information along with authorship
// and copyright notices in any redistribution of this code
// **********************************************************************************
#include <SensorIoTNode.h>

void setup(void)
{

#ifdef SERIAL_EN
  Serial.begin(SERIAL_BAUD);
#endif

  pinMode(LED, OUTPUT);

  DEBUG("SensorIoT NodeID ");
  DEBUG(NODE_ID);
  DEBUG(" GW: ");
  DEBUG(GATEWAY_ID);
  DEBUG(" SW VER: ");
  DEBUGln(VERSION);
  
  //DEBUGln("Setting up device");

  enablePowerBoost(); //enable the power boost circuit during setup and initialization
  
  secsBetweenXmit = SECSBETWEENXMITS;

  //Set the node status bits
  nodeStatus |= NODESTATUS_FIRSTLOOP; //startup is true

  //initialize weather shield BME280 sensor
  bme280.settings.commInterface = I2C_MODE;
  bme280.settings.I2CAddress = 0x77;
  bme280.settings.runMode = 3; //Normal mode
  bme280.settings.tStandby = 0;
  bme280.settings.filter = 0;
  bme280.settings.tempOverSample = 1;
  bme280.settings.pressOverSample = 1;
  bme280.settings.humidOverSample = 1;

  //DEBUGln("Init and sleep BME280");

  
  bme280.begin();
  P = bme280.readFloatPressure() * 0.0002953; //read Pa and convert to inHg
  F = bme280.readTempF();
  H = bme280.readFloatHumidity();
  bme280.writeRegister(BME280_CTRL_MEAS_REG, 0x00); //sleep the BME280
  
  
  //DEBUGln("Blinking LED");
  
  Blink(LED, 100);Blink(LED, 100);Blink(LED, 100);

  //DEBUGln("Init radio");

  
  if(!radio.init()) {
    //DEBUGln("Radio init failed");
  } else
  {
    //DEBUGln("Radio initialization succeeded");
  }
    
  driver.setFrequency(FREQUENCY);
  _txPower=(MAXTXPOWER-MINTXPOWER)/2+MINTXPOWER; //Start at a midpoint for xmit power.
  //DEBUG("Setting tx power to ");
  //DEBUGln(_txPower);
  #ifdef IS_RF95
    driver.setModemConfig(RF95_MODEM_CONFIG);
    driver.setTxPower(_txPower,false); //Tx power can be set from 5 to 23db
    radio.setRetries(2); //The number of times to retry to contact the GW if the initial send fails.
    radio.setTimeout(1000);
  #endif
  #ifdef IS_RFM69HW
    //driver.setModemConfig(RH_RF69::GFSK_Rb2Fd5);
    driver.setTxPower(_txPower,true); //Tx power can be set from -2 to 20db
    radio.setRetries(5); //The number of times to try to contact the server
    radio.setTimeout(500); //Millis to wait for an ACK. Tune for a particular modem config.
  #endif

  //DEBUG("Transmitting at: ");
  //DEBUGln(FREQUENCY);
  //DEBUGln(" Mhz");

//  radio.setHeaderFrom(NODE_ID);
  SERIALFLUSH();
  driver.sleep();

}

void loop() {
  DEBUGln("Start Loop");
  printMillis();
  enablePowerBoost();
  nodeStatus &= ~NODESTATUS_XMIT_SUCCESS;
  printMillis(); //4
  if((secsSinceXmit >= secsBetweenXmit) || (nodeStatus & NODESTATUS_FIRSTLOOP)) {
    Blink(LED, 8); 
  printMillis(); //8
    readBattery(); 
  printMillis(); //2
    
    //read BME sensor
    bme280.begin();
    P = bme280.readFloatPressure() * 0.0002953; //read Pa and convert to inHg
    F = bme280.readTempF();
    H = bme280.readFloatHumidity();
    bme280.writeRegister(BME280_CTRL_MEAS_REG, 0x00); //sleep the BME280
  printMillis(); //37

    //The numbers need to be left justified
    dtostrf(F, -1,2, Fstr);
    dtostrf(H, -1,2, Hstr);
    dtostrf(P, -1,2, Pstr);
    dtostrf(_txPower, -1,0, TxStr);
    dtostrf(nodeStatus, -1,0, STStr);

    sprintf((char*)buffer, "BAT:%sv F:%s H:%s P:%s TX:%s ST:%s", BATstr, (char*)Fstr, (char*)Hstr, (char*)Pstr, (char*)TxStr, (char*)STStr);
//    sprintf((char*)buffer, "BAT:%sv F:%s H:%s P:%s", BATstr, (char*)Fstr, (char*)Hstr, (char*)Pstr);

  printMillis(); //2

    DEBUG("Sending ");
    DEBUGln((char*)buffer);

    DEBUG("loopCounter: ");
    DEBUGln(loopCounter);

    if(loopCounter <= LOOPSWITHACK) {
      sendWithCtrlMsg();//346
      nodeStatus |= NODESTATUS_WAIT_FOR_ACK;
    } else {
      sendWithoutCtrlMsg();//10
      nodeStatus &= ~NODESTATUS_WAIT_FOR_ACK;
    }
  printMillis(); 

      //DEBUGln("sleeping");
    secsSinceXmit = 0;
    delay(3); //Give the power boost a few millis to top off the cap before shutdown.
    driver.sleep();

    //if we have 10 successful xmit loops at the current sleep level, move up to the next level
    if(nodeStatus & NODESTATUS_XMIT_SUCCESS) {
      loopSuccess++;
      loopCounter++;
    }
    if(loopSuccess >= 5) {
      setNextSleepTime();
      loopSuccess = 0;
    }
  } else {
    secsSinceXmit+=getCurrentSleepTime();
  }
  printMillis(); //4

  disablePowerBoost();
  DEBUGln("End Loop");
  SERIALFLUSH();
  LowPower.powerDown(currentSleepTime, ADC_OFF, BOD_OFF);
  nodeStatus &= ~NODESTATUS_FIRSTLOOP; //set status for firstloop to false

}

void sendWithCtrlMsg() {
  sendLen = strlen((char*)buffer);
  // Send a message to radio_server
  DEBUG("sendWithCtrlMsg: ");
  DEBUGln((char*)buffer);

  if (radio.sendtoWait(buffer, sendLen, GATEWAY_ID)) {
//          DEBUG("SendtoWait succeeded with ");
//          DEBUG(radio.retransmissions());
//          DEBUGln(" retransmissions");
  // Now wait for a reply from the server
    uint8_t len = sizeof(buffer);
    uint8_t from;   
    if (radio.recvfromAckTimeout(buffer, &len, 3000, &from))
    {
      DEBUG("Control msg from GW: ");
      DEBUG((char*)buffer);
      DEBUG(" RSSI: ");
      DEBUGln(driver.lastRssi());
      handleControlMsg((char*)buffer);
      nodeStatus |= NODESTATUS_XMIT_SUCCESS;
    }
    else
    {
      DEBUGln("No CtrlMsg");
    }
  }
  else {
    DEBUG("SendtoWait FAILED");
//    DEBUG(radio.retransmissions());
//    DEBUGln(" retransmissions");
//    radio.resetRetransmissions();
    if(_txPower < MAXTXPOWER) {
      _txPower++;
      nodeStatus &= ~NODESTATUS_MAX_POWER;
    } else {
      nodeStatus |= NODESTATUS_MAX_POWER;
    }
    driver.setTxPower(_txPower);
    DEBUG("NOACK Pwr:");
    DEBUGln(_txPower);
  }

}

void sendWithoutCtrlMsg() {
  sendLen = strlen((char*)buffer);
  DEBUG("sendWithoutCtrlMsg: ");
  DEBUGln((char*)buffer);
  //Because we're effectively changing from RHReliableDatagram to RHDatagram
  //when we want to stop waiting for ACKs, we need to start managing some of the
  //header data ourselves. 
  radio.setHeaderFlags(RH_FLAGS_NONE, RH_FLAGS_ACK); // Clear the ACK flag
	radio.setHeaderId(loopSuccess); //Make sure we dont send the same seq num
  if (radio.sendto(buffer, sendLen, GATEWAY_ID)) {
    nodeStatus |= NODESTATUS_XMIT_SUCCESS;
  }
}

uint8_t getCurrentSleepTime() {
  switch((uint8_t)currentSleepTime) {
    case SLEEP_15MS:
      return 0;
    case SLEEP_250MS:
      return 0;
    case SLEEP_1S:
      return 1;
    case SLEEP_2S:
      return 2;
    case SLEEP_4S:
      return 4;
    case SLEEP_8S:
      return 8;
  }

  return 0; //Shouldnt get here :P
}
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

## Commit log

2018-06-01 initial push
    [GDEnvSensorNode_1_3b.brd, GDEnvSensorNode_1_3b.sch, GDEnvSensorNode_1_4b.brd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]
2019-06-20 bring PCS up to date to 1.4h
    [GDEnvSensorNode_1_3c.brd, GDEnvSensorNode_1_3c.sch, GDEnvSensorNode_1_4c.brd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]
2019-06-20 Initial release of controllable boost power node
2019-10-18 Reorg and RFM95 support
    [GDEnvSensorNode_1_5.brd, GDEnvSensorNode_1_5.sch, SensorIoT_Node_Programmer.brd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]
2026-03-19 Add deprecation notice — code moved to SensorIoT-GW repo
    https://claude.ai/code/session_0171vFeZAqu7LSvjEKnyn65i

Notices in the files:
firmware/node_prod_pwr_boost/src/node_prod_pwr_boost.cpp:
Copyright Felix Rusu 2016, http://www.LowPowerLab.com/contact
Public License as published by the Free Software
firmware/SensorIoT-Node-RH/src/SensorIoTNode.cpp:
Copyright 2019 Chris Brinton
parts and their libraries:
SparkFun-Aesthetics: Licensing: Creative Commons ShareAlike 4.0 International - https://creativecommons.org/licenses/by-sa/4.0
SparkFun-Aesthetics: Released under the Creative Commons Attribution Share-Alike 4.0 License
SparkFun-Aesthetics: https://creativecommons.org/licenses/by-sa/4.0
